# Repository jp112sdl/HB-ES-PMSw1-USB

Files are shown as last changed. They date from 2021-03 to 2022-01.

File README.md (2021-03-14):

# HB-ES-PMSw1-USB
Homebrew Homematic USB Strom-/Spannungsmesser mit INA219

Benötigt [JP-HB-Devices Addon mind. V 4.2](https://github.com/jp112sdl/JP-HB-Devices-addon/releases)

In der Arduino IDE muss noch folgende Lib eingebunden werden:
- https://github.com/jp112sdl/INA219_WE

### Aktueller Stand (14.03.2021):
- CCU Unterstützung bereitgestellt (Addon V 4.2)
- Sketch lauffähig

### schematischer Schaltungsaufbau
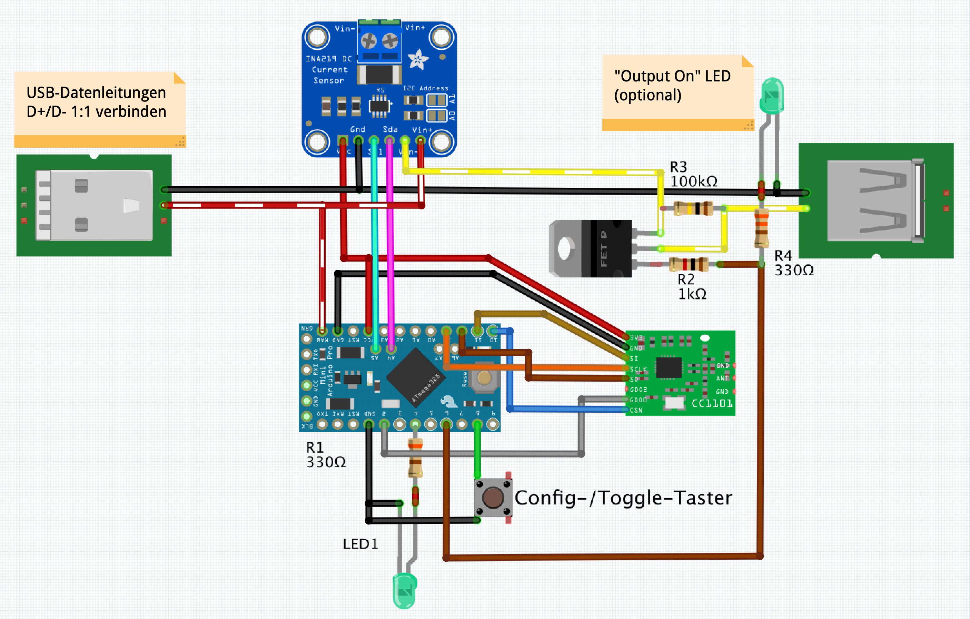
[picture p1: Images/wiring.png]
wiring


###  🚧 PCB - WORK IN PROGRESS

Projekt-Thread im HomeMatic-Forum: https://homematic-forum.de/forum/viewtopic.php?f=76&t=66307

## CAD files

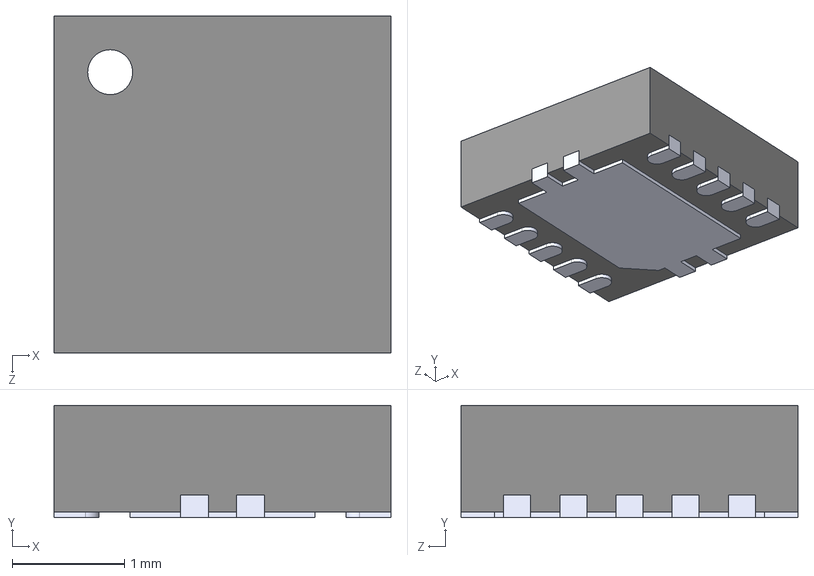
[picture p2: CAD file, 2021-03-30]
PCB/additional/SON50P300X300X100-11N.step
3.00 x 1.00 x 3.00 mm

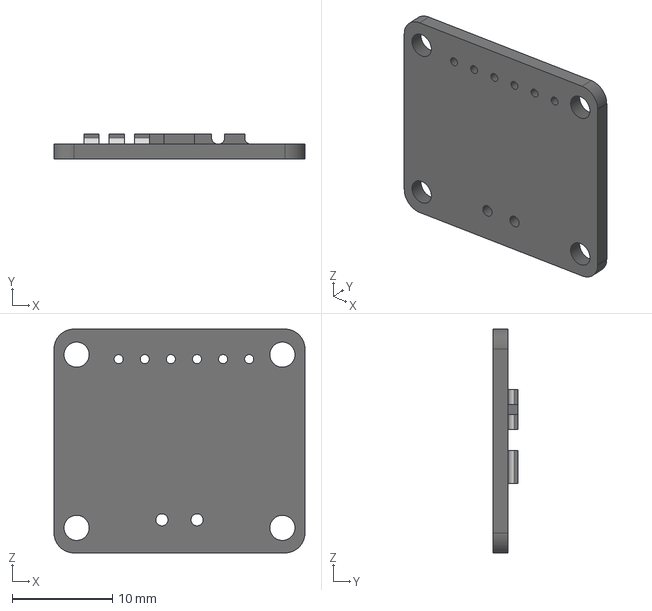
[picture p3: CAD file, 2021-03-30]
PCB_ProMini/additional/CJMCU-219 INA219.step
25.0 x 2.50 x 22.3 mm

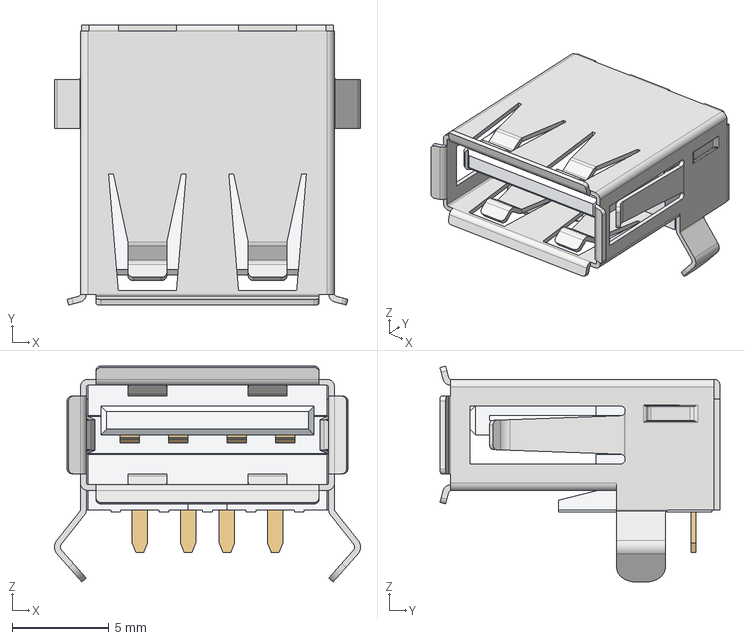
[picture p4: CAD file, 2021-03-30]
PCB/additional/femaleThruHoleUSB.stp
15.8 x 14.4 x 11.1 mm

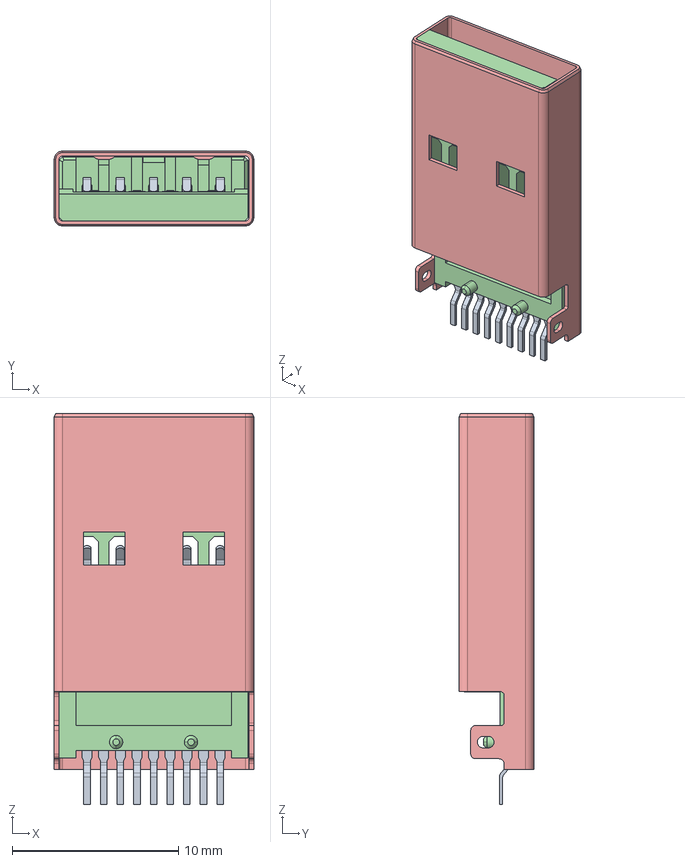
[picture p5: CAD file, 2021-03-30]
PCB_ProMini/additional/usb-male.stp
12.0 x 4.50 x 23.5 mm
CONTACT_5-1
CONTACT-1-1
CONTACT-2-1
CONTACT-3-1
CONTACT-4-1
HOUSING-1
SHELL-SA-1

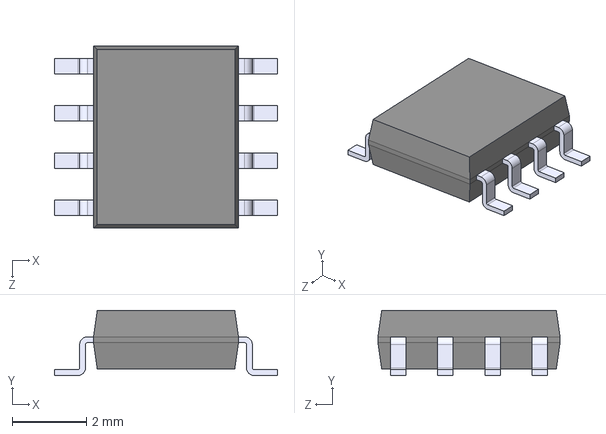
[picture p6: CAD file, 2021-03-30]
PCB/additional/SI9933CDY.STEP
6.00 x 1.75 x 4.90 mm

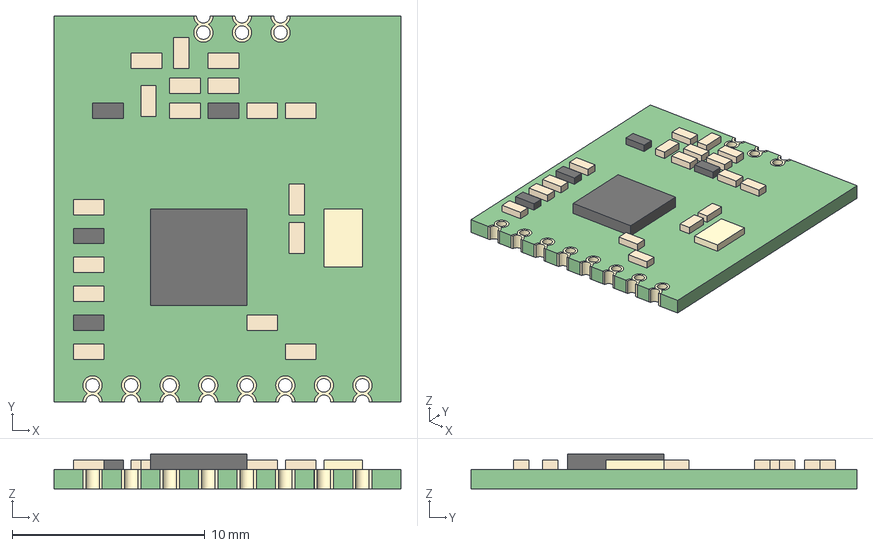
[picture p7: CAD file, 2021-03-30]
PCB/additional/CC1101_Module.step
18.0 x 20.0 x 1.80 mm
PCB
Parts
Pads

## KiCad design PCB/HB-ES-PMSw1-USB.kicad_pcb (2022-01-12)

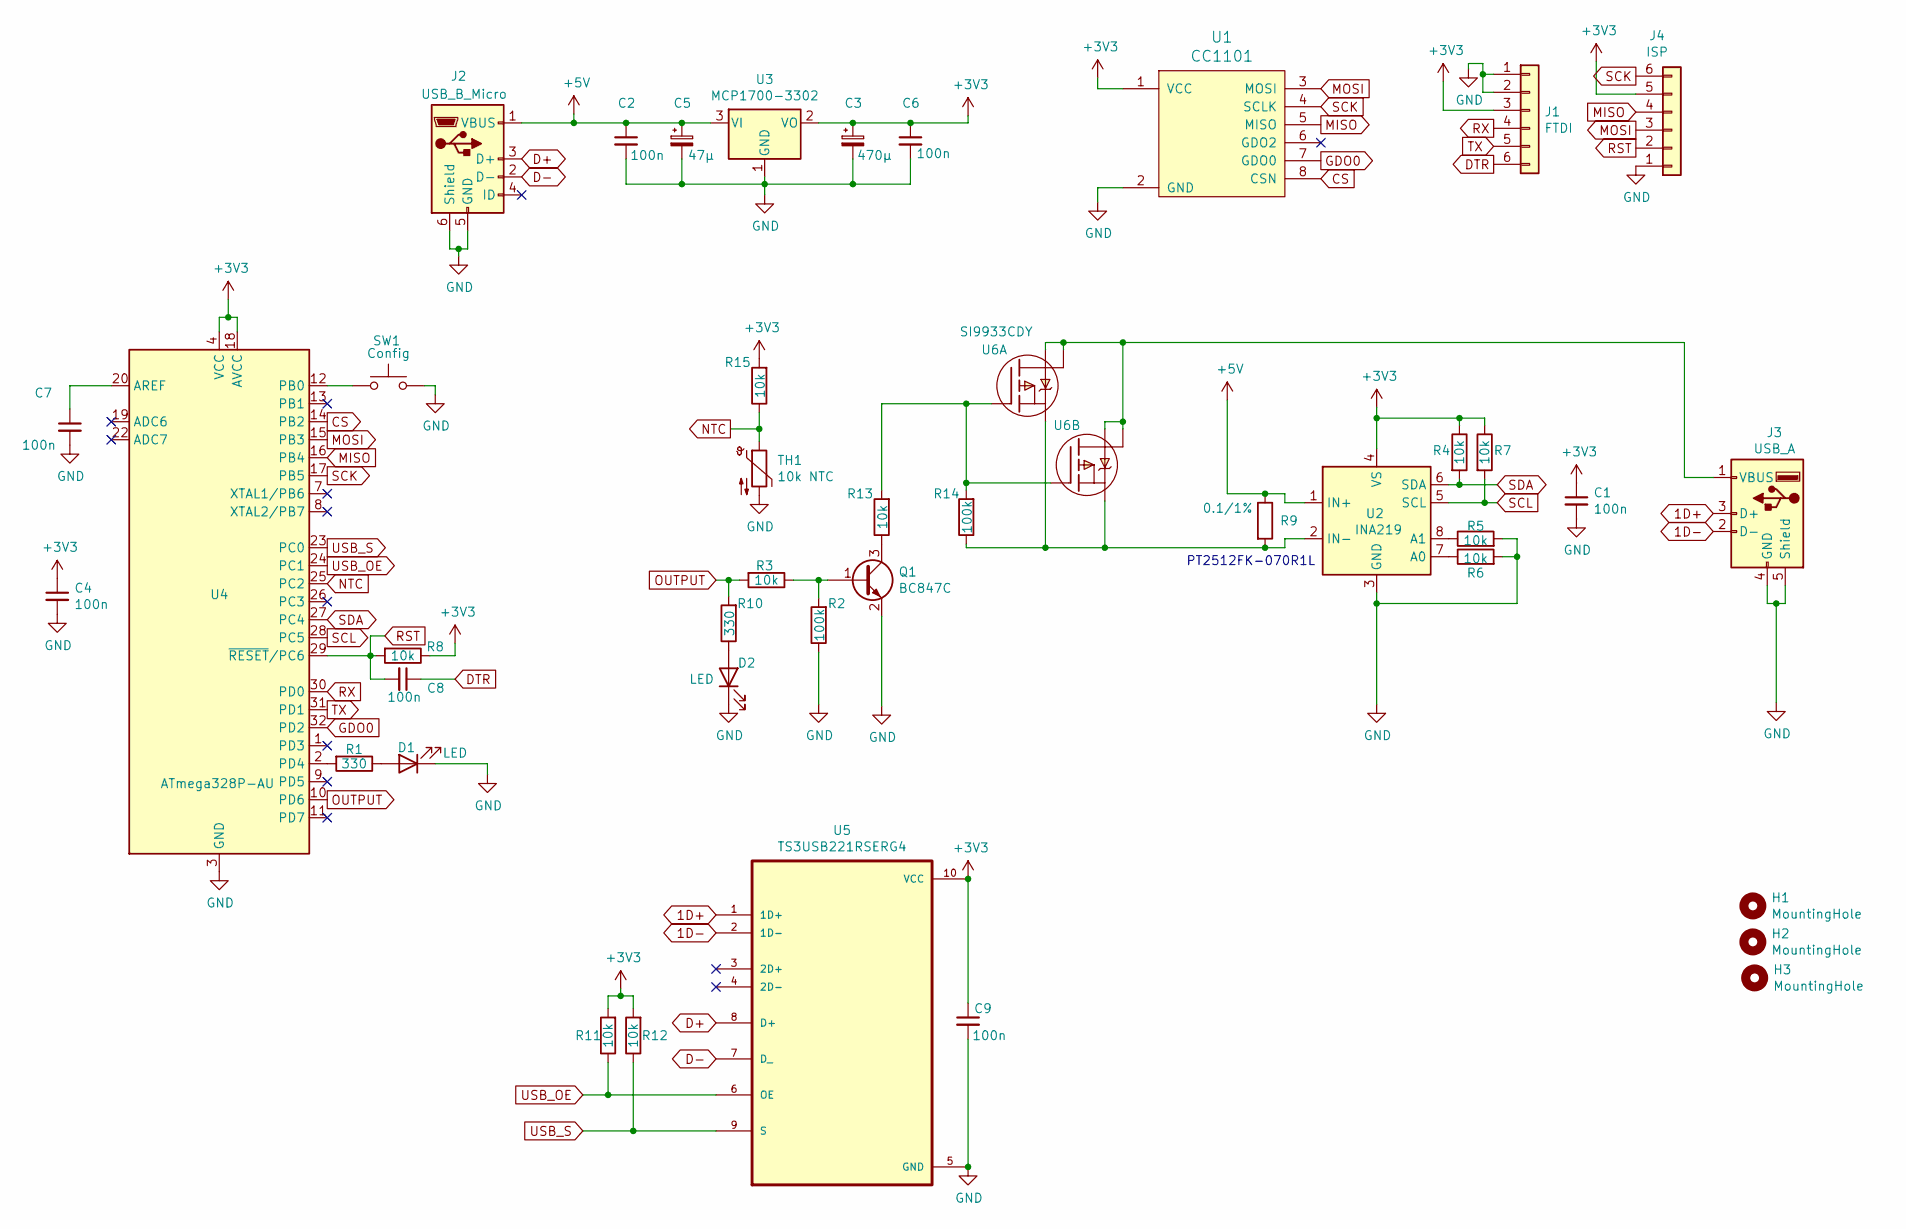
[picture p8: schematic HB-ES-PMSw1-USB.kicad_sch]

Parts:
C1, C2, C4, C6, C7, C8, C9: 100n; C_0805_2012Metric_Pad1.15x1.40mm_HandSolder
C3: 470µ; CP_Elec_8x10.5
C5: 47µ; CP_Elec_8x5.4
D1, D2: LED; LED_0805_2012Metric_Pad1.15x1.40mm_HandSolder
H1, H2, H3: MountingHole; MountingHole_2.7mm_M2.5
J1: FTDI; PinHeader_1x06_P2.54mm_Vertical
J2: USB_B_Micro; USB_Micro-B_Molex-105017-0001
J3: USB_A
J4: ISP; PinPads_ISP
Q1: BC847C; SOT-23
R1, R10: 330; R_0805_2012Metric_Pad1.15x1.40mm_HandSolder
R2, R14: 100k; R_0805_2012Metric_Pad1.15x1.40mm_HandSolder
R3, R4, R5, R6, R7, R8, R11, R12, R13, R15: 10k; R_0805_2012Metric_Pad1.15x1.40mm_HandSolder
R9: 0.1/1%; R_2512_6332Metric_Pad1.52x3.35mm_HandSolder
SW1: Config; SW_PUSH_6mm_H5mm
TH1: 10k NTC; R_0805_2012Metric_Pad1.15x1.40mm_HandSolder
U1: CC1101; CC1101_SMD
U2: INA219; SOT-23-8
U3: MCP1700-3302; SOT-23
U4: ATmega328P-AU; TQFP-32_7x7mm_P0.8mm
U5: TS3USB221RSERG4; SON50P300X300X100-11N
U6: SI9933CDY; SO8-2

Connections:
1D+: J3.3 (D+), U5.1 (1D+)
1D-: J3.2 (D-), U5.2 (1D-)
+3V3: C1.1, C3.1, C4.1, C6.1, C9.1, J1.3, J4.5, R4.1, R7.1, R8.1, R11.2, R12.2, R15.2, U1.1 (VCC), U2.4 (VS), U3.2 (VO), U4.4 (VCC), U4.6 (VCC), U4.18 (AVCC), U5.10 (VCC)
+5V: C2.1, C5.1, J2.1 (VBUS), R9.1, U2.1 (IN+), U3.3 (VI)
CS: U1.8 (CSN), U4.14 (PB2)
D+: J2.3 (D+), U5.8 (D+)
D-: J2.2 (D-), U5.7 (D_)
DTR: C8.1, J1.6
GDO0: U1.7 (GDO0), U4.32 (PD2)
GND: C1.2, C2.2, C3.2, C4.2, C5.2, C6.2, C7.2, C9.2, D1.1 (K), D2.1 (K), J1.1, J1.2, J2.5 (GND), J2.6 (Shield), J3.4 (GND), J3.5 (Shield), J4.1, Q1.2 (E), R2.1, R5.2, R6.2, SW1.2, TH1.2, U1.2 (GND), U2.3 (GND), U3.1 (GND), U4.3 (GND), U4.5 (GND), U4.21 (GND), U5.5 (GND)
MISO: J4.4, U1.5 (MISO), U4.16 (PB4)
MOSI: J4.3, U1.3 (MOSI), U4.15 (PB3)
NTC: R15.1, TH1.1, U4.25 (PC2)
unnamed: C7.1, U4.20 (AREF)
unnamed: D1.2 (A), R1.1
unnamed: D2.2 (A), R10.1
unnamed: J3.1 (VBUS), U6.5, U6.6, U6.7, U6.8
unnamed: Q1.1 (B), R2.2, R3.1
unnamed: Q1.3 (C), R13.1
unnamed: R1.2, U4.2 (PD4)
unnamed: R5.1, U2.8 (A1)
unnamed: R6.1, U2.7 (A0)
unnamed: R13.2, R14.2, U6.2, U6.4
unnamed: R9.2, R14.1, U2.2 (IN-), U6.1, U6.3
unnamed: SW1.1, U4.12 (PB0)
OUTPUT: R3.2, R10.2, U4.10 (PD6)
RST: C8.2, J4.2, R8.2, U4.29 (~RESET/PC6)
RX: J1.4, U4.30 (PD0)
SCK: J4.6, U1.4 (SCLK), U4.17 (PB5)
SCL: R7.2, U2.5 (SCL), U4.28 (PC5)
SDA: R4.2, U2.6 (SDA), U4.27 (PC4)
TX: J1.5, U4.31 (PD1)
USB_OE: R11.1, U4.24 (PC1), U5.6 (OE)
USB_S: R12.1, U4.23 (PC0), U5.9 (S)

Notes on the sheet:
PT2512FK-070R1L

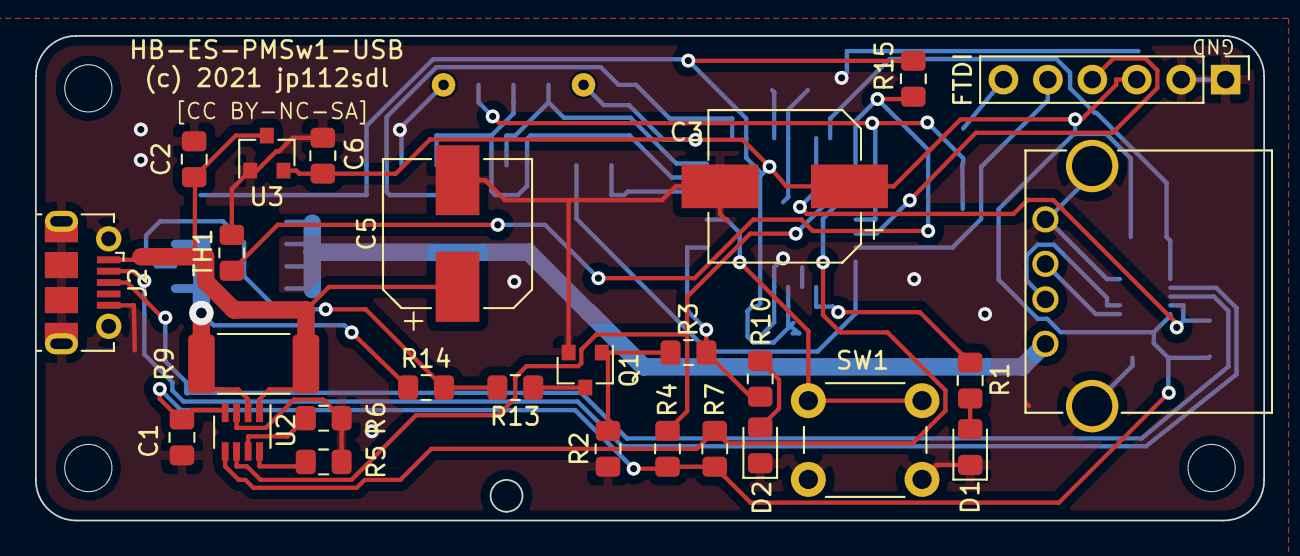
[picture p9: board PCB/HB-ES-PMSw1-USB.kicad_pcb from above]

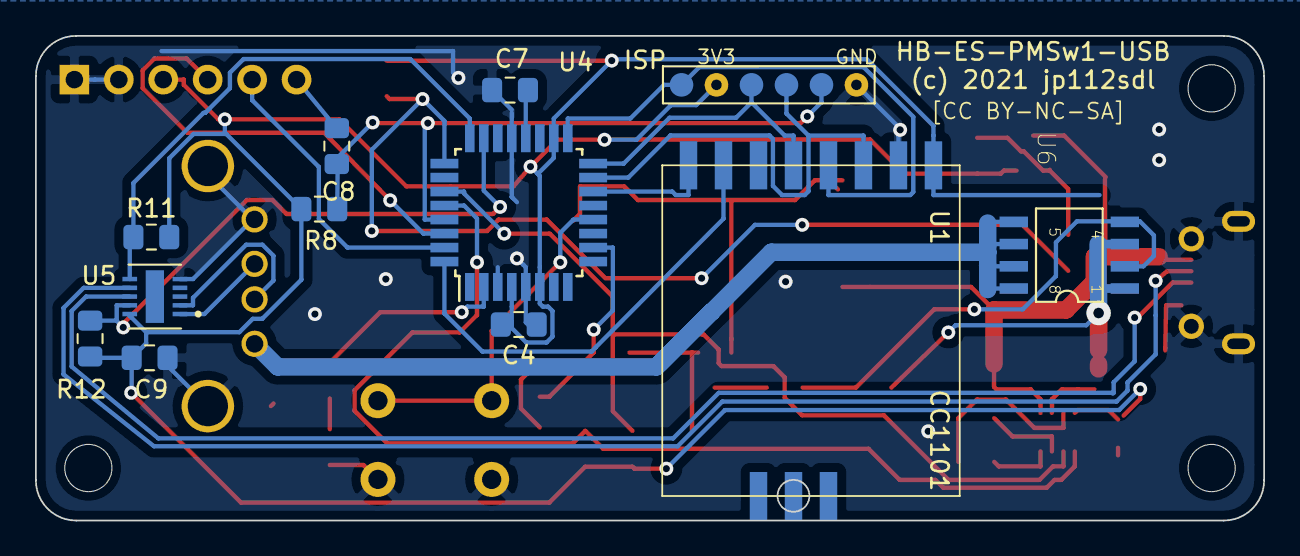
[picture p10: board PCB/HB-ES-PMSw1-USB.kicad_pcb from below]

Board: 2 copper layers, 70.2 x 27.7 mm, 42 parts (12 on the bottom side), 34 nets.

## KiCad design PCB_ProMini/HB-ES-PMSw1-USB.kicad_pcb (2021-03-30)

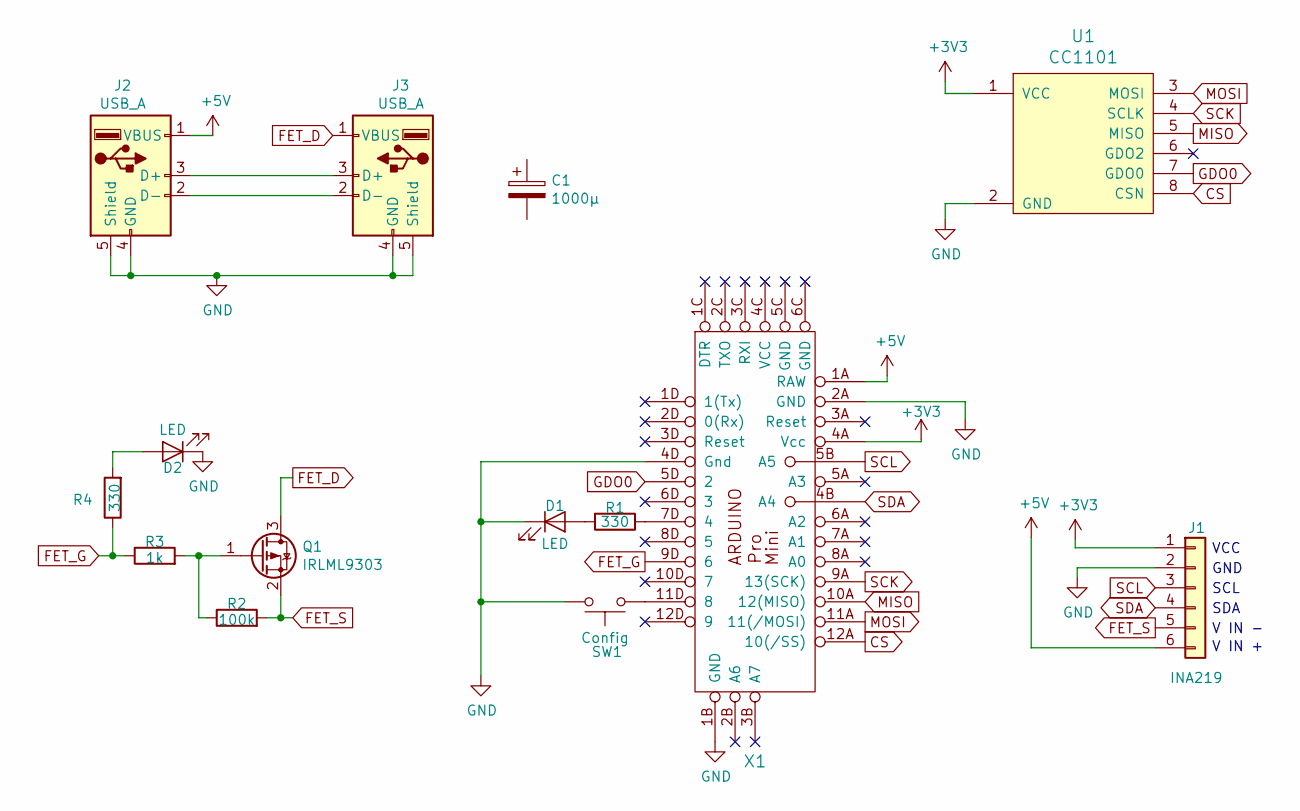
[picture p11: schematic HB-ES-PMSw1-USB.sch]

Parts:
C1: 1000µ; CP_Axial_L29.0mm_D13.0mm_P35.00mm_Horizontal
D1, D2: LED; LED_D3.0mm
J1: INA219; PinHeader_1x06_P2.54mm_Vertical
J2, J3: USB_A
Q1: IRLML9303; TO-220-3_Horizontal_TabDown
R1, R4: 330; R_Axial_DIN0204_L3.6mm_D1.6mm_P7.62mm_Horizontal
R2: 100k; R_Axial_DIN0204_L3.6mm_D1.6mm_P2.54mm_Vertical
R3: 1k; R_Axial_DIN0204_L3.6mm_D1.6mm_P2.54mm_Vertical
SW1: Config; SW_PUSH_6mm_H5mm
U1: CC1101
X1: Arduino_Pro_Mini

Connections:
+3V3: J1.1, U1.1 (VCC), X1.4A (Vcc)
+5V: J1.6, J2.1 (VBUS), X1.1A (RAW)
CS: U1.8 (CSN), X1.12A (10(/SS))
FET_D: J3.1 (VBUS), Q1.3 (D)
FET_G: R3.1, R4.1, X1.9D (6)
FET_S: J1.5, Q1.2 (S), R2.2
GDO0: U1.7 (GDO0), X1.5D (2)
GND: D1.1 (K), D2.1 (K), J1.2, J2.4 (GND), J2.5 (Shield), J3.4 (GND), J3.5 (Shield), SW1.2, U1.2 (GND), X1.1B (GND), X1.2A (GND), X1.4D (Gnd)
MISO: U1.5 (MISO), X1.10A (12(MISO))
MOSI: U1.3 (MOSI), X1.11A (11(/MOSI))
unnamed: D1.2 (A), R1.2
unnamed: D2.2 (A), R4.2
unnamed: J2.2 (D-), J3.2 (D-)
unnamed: J2.3 (D+), J3.3 (D+)
unnamed: Q1.1 (G), R2.1, R3.2
unnamed: R1.1, X1.7D (4)
unnamed: SW1.1, X1.11D (8)
SCK: U1.4 (SCLK), X1.9A (13(SCK))
SCL: J1.3, X1.5B (A5)
SDA: J1.4, X1.4B (A4)

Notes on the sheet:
GND
VCC
SCL
SDA
V IN +
V IN -

Board: 2 copper layers, 13 parts (2 on the bottom side), 20 nets, no tracks yet.

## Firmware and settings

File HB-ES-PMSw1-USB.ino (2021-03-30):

//- -----------------------------------------------------------------------------------------------------------------------
// AskSin++
// 2017-10-24 papa Creative Commons - http://creativecommons.org/licenses/by-nc-sa/3.0/de/
// 2021-03-06 jp112sdl Creative Commons - http://creativecommons.org/licenses/by-nc-sa/3.0/de/
//- -----------------------------------------------------------------------------------------------------------------------
// ci-test=yes board=328p aes=no

// define this to read the device id, serial and device type from bootloader section
// #define USE_OTA_BOOTLOADER
// #define NDEBUG
#define HIDE_IGNORE_MSG

#define EI_NOTEXTERNAL
#include <EnableInterrupt.h>
#include <AskSinPP.h>
#include <LowPower.h>
#include <Switch.h>
#include <INA219_WE.h> //https://github.com/jp112sdl/INA219_WE

#define MEASURE_INTERVAL            1
#define POWERMETER_CYCLIC_INTERVAL  120

#define SWITCH_PIN          6
#define INVERT_SWITCH_PIN   true //true = ACTIVE LOW
#define BUTTON_PIN          8
#define LED_PIN             4
#define NTC                A2

#define USB_OE             A1
#define USB_S              A0

// number of available peers per channel
#define PEERS_PER_SWCHANNEL     8
#define PEERS_PER_PMCHANNEL     8
#define PEERS_PER_SENSORCHANNEL 8

// all library classes are placed in the namespace 'as'
using namespace as;

typedef struct {
  uint16_t Current   = 0;
  uint16_t Voltage   = 0;
} sensorValues;

sensorValues actualValues ;
sensorValues lastValues;
uint8_t averaging = 1;
bool    resetAverageCounting = false;
// define all device properties
const struct DeviceInfo PROGMEM devinfo = {
  {0xf3, 0x5a, 0x01},     // Device ID
  "HBPMSwUSB0",           // Device Serial
  {0xf3, 0x5a},           // Device Model
  0x10,                   // Firmware Version
  as::DeviceType::Switch, // Device Type
  {0x01, 0x00}            // Info Bytes
};

// Configure the used hardware
typedef AvrSPI<10, 11, 12, 13> RadioSPI;
typedef AskSin<StatusLed<LED_PIN>, NoBattery, Radio<RadioSPI, 2> > Hal;
Hal hal;

DEFREGISTER(Reg0, MASTERID_REGS, DREG_INTKEY, DREG_LOCALRESETDISABLE)
class PMSw1List0 : public RegList0<Reg0> {
  public:
    PMSw1List0(uint16_t addr) : RegList0<Reg0>(addr) {}
    void defaults () {
      clear();
    }
};

bool outputOn() {
  return (digitalRead(SWITCH_PIN) == (INVERT_SWITCH_PIN == true ? LOW:HIGH));
}

class TS3USB221 {
public:
  void init() {
    pinMode(USB_OE, OUTPUT);
    pinMode(USB_S,  OUTPUT);

    //set initial state
    digitalWrite(USB_OE, HIGH);
    digitalWrite(USB_S,  LOW);
  }

  void enable() {
    digitalWrite(USB_OE, LOW);
  }

  void disable() {
    digitalWrite(USB_OE, HIGH);
  }

  void enableD1() {
    enable();
    digitalWrite(USB_S, LOW);
  }

  void enableD2() {
    enable();
    digitalWrite(USB_S, HIGH);
  }
};

class SwChannel : public SwitchChannel<Hal, PEERS_PER_SWCHANNEL, PMSw1List0>  {
  protected:
    typedef SwitchChannel<Hal, PEERS_PER_SWCHANNEL, PMSw1List0> BaseChannel;
    TS3USB221 ts3usb221;

  public:
    SwChannel () : BaseChannel() {}
    virtual ~SwChannel() {}


    void init (uint8_t p, bool inv) {
      ts3usb221.init();
      BaseChannel::init(p, inv);
    }

    virtual void switchState(__attribute__((unused)) uint8_t oldstate, uint8_t newstate,uint32_t delay) {
      BaseChannel::switchState(oldstate, newstate, delay);
      if ( newstate == AS_CM_JT_ON ) {
        resetAverageCounting = true;
        ts3usb221.enableD1();
      }
      else if ( newstate == AS_CM_JT_OFF ) {
        ts3usb221.disable();
      }
    }
};
DEFREGISTER(MReg1, CREG_AES_ACTIVE, CREG_AVERAGING, CREG_TX_MINDELAY, CREG_TX_THRESHOLD_CURRENT, CREG_TX_THRESHOLD_VOLTAGE )
class MeasureList1 : public RegList1<MReg1> {
  public:
    MeasureList1 (uint16_t addr) : RegList1<MReg1>(addr) {}
    void defaults () {
      clear();
      txMindelay(8);
      txThresholdCurrent(100);
      txThresholdVoltage(100);
      averaging(1);
    }
};

DEFREGISTER(SensorReg1, CREG_AES_ACTIVE, CREG_LEDONTIME, CREG_TRANSMITTRYMAX, CREG_COND_TX_THRESHOLD_HI, CREG_COND_TX_THRESHOLD_LO, CREG_COND_TX, CREG_COND_TX_DECISION_ABOVE, CREG_COND_TX_DECISION_BELOW)
class SensorList1 : public RegList1<SensorReg1> {
  public:
    SensorList1 (uint16_t addr) : RegList1<SensorReg1>(addr) {}
    void defaults () {
      clear();
      transmitTryMax(6);
      condTxDecisionAbove(200);
      condTxDecisionBelow(0);
      condTxFalling(false);
      condTxRising(false);
      condTxCyclicBelow(false);
      condTxCyclicAbove(false);
      condTxThresholdHi(0);
      condTxThresholdLo(0);
    }
};

class PowerEventMsg : public Message {
  public:
    void init(uint8_t msgcnt, uint8_t typ, uint16_t current, uint16_t voltage ) {
      Message::init(0x0d, msgcnt, typ, (typ == AS_MESSAGE_POWER_EVENT_CYCLIC) ? BCAST : BIDI | BCAST, (current >> 8), (current) & 0xff);
      pload[0] = (voltage >> 8) & 0xff;
      pload[1] = (voltage) & 0xff;
    }
};

class PowerMeterChannel : public Channel<Hal, MeasureList1, EmptyList, List4, PEERS_PER_PMCHANNEL, PMSw1List0>, public Alarm {
    PowerEventMsg msg;
    uint16_t txThresholdCurrent;
    uint16_t txThresholdVoltage;
    uint8_t txMindelay;
  public:
    PowerMeterChannel () : Channel(), Alarm(0), txThresholdCurrent(0), txThresholdVoltage(0), txMindelay(8) {}
    virtual ~PowerMeterChannel () {}
    virtual void trigger (__attribute__ ((unused)) AlarmClock& clock) {
      static uint8_t tickCount = 0;
      tick = seconds2ticks(delay());
      tickCount++;

      uint8_t msgType = 0;

      if (tickCount > (POWERMETER_CYCLIC_INTERVAL / delay()))  {
        msgType = AS_MESSAGE_POWER_EVENT_CYCLIC;
      }

      if ((txThresholdCurrent   > 0) && (abs((int)(actualValues.Current   - lastValues.Current)  ) >= (int)txThresholdCurrent))   msgType = AS_MESSAGE_POWER_EVENT;
      if ((txThresholdVoltage   > 0) && (abs((int)(actualValues.Voltage   - lastValues.Voltage)  ) >= (int)txThresholdVoltage))   msgType = AS_MESSAGE_POWER_EVENT;

      if ((msgType != AS_MESSAGE_POWER_EVENT) && (actualValues.Current > 0) && (lastValues.Current == 0)) msgType = AS_MESSAGE_POWER_EVENT;
      msg.init(device().nextcount(), msgType, actualValues.Current, actualValues.Voltage);
      switch (msgType) {
        case AS_MESSAGE_POWER_EVENT_CYCLIC:
          DPRINTLN(F("PowerMeterChannel - SENDING CYCLIC MESSAGE"));
          tickCount = 0;
          device().broadcastEvent(msg);
          break;
        case AS_MESSAGE_POWER_EVENT:
          if (device().getMasterID() > 0) {
            DPRINTLN(F("PowerMeterChannel - SENDING EVENT MESSAGE"));
            device().sendMasterEvent(msg);
          }
          break;
      }

      lastValues.Current = actualValues.Current;
      lastValues.Voltage = actualValues.Voltage;

      sysclock.add(*this);
    }

    uint32_t delay() {
      return max(1, txMindelay);
    }

    void configChanged() {
      DPRINTLN(F("PowerMeterChannel Config changed List1"));
      txThresholdCurrent   = this->getList1().txThresholdCurrent();      // 1 mA   = 1
      txThresholdVoltage   = this->getList1().txThresholdVoltage();      // 10.0V  = 100
      txMindelay           = this->getList1().txMindelay();
      averaging            = this->getList1().averaging();
      DPRINT(F("txMindelay           = ")); DDECLN(txMindelay);
      DPRINT(F("txThresholdCurrent   = ")); DDECLN(txThresholdCurrent);
      DPRINT(F("txThresholdVoltage   = ")); DDECLN(txThresholdVoltage);
    }

    void setup(Device<Hal, PMSw1List0>* dev, uint8_t number, uint16_t addr) {
      Channel::setup(dev, number, addr);
      sysclock.add(*this);
    }

    uint8_t status () const {
      return 0;
    }

    uint8_t flags () const {
      return 0;
    }
};

class SensorChannel : public Channel<Hal, SensorList1, EmptyList, List4, PEERS_PER_SENSORCHANNEL, PMSw1List0>, public Alarm {
  public:

    SensorChannel () : Channel(), Alarm(0) {}
    virtual ~SensorChannel () {}

    virtual void trigger (__attribute__ ((unused)) AlarmClock& clock) {
      static uint8_t evcnt = 0;
      bool sendMsg = false;
      tick = seconds2ticks(10);

      if (outputOn() == true) {
        SensorEventMsg& rmsg = (SensorEventMsg&)device().message();
        static uint8_t aboveMsgSent = false;
        static uint8_t belowMsgSent = false;
        switch (number()) {
          case 3:
            // Stromsensor
            if (this->getList1().condTxRising() == true)  {
              if (actualValues.Current > this->getList1().condTxThresholdHi()) {
                if ((aboveMsgSent == false && this->getList1().condTxCyclicAbove() == false) || this->getList1().condTxCyclicAbove() == true) {
                  //DPRINT(F("SensorChannel Strom - SENDING condTxRising "));DDECLN(this->getList1().condTxDecisionAbove());
                  rmsg.init(device().nextcount(), number(), evcnt++, this->getList1().condTxDecisionAbove(), false , false);
                  sendMsg = true;
                  aboveMsgSent = true;
                }
              } else {
                aboveMsgSent = false;
              }
            }
            if (this->getList1().condTxFalling() == true) {
              if (actualValues.Current < this->getList1().condTxThresholdLo()) {
                if ((belowMsgSent == false && this->getList1().condTxCyclicBelow() == false) || this->getList1().condTxCyclicBelow() == true) {
                  //DPRINT(F("SensorChannel Strom - SENDING condTxFalling "));DDECLN(this->getList1().condTxDecisionBelow());
                  rmsg.init(device().nextcount(), number(), evcnt++, this->getList1().condTxDecisionBelow(), false , false);
                  sendMsg = true;
                  belowMsgSent = true;
                }
              } else {
                belowMsgSent = false;
              }
            }
            break;
          case 4:
            // Spannungssensor
            if (this->getList1().condTxRising() == true)  {
              if (actualValues.Voltage > this->getList1().condTxThresholdHi()) {
                if ((aboveMsgSent == false && this->getList1().condTxCyclicAbove() == false) || this->getList1().condTxCyclicAbove() == true) {
                  //DPRINT(F("SensorChannel Spannung - SENDING condTxRising "));DDECLN(this->getList1().condTxDecisionAbove());
                  rmsg.init(device().nextcount(), number(), evcnt++, this->getList1().condTxDecisionAbove(), false , false);
                  sendMsg = true;
                  aboveMsgSent = true;
                }
              } else {
                aboveMsgSent = false;
              }
            }
            if (this->getList1().condTxFalling() == true) {
              if (actualValues.Voltage < this->getList1().condTxThresholdLo()) {
                if ((belowMsgSent == false && this->getList1().condTxCyclicBelow() == false) || this->getList1().condTxCyclicBelow() == true) {
                  //DPRINT(F("SensorChannel Spannung - SENDING condTxFalling "));DDECLN(this->getList1().condTxDecisionBelow());
                  rmsg.init(device().nextcount(), number(), evcnt++, this->getList1().condTxDecisionBelow(), false , false);
                  sendMsg = true;
                  belowMsgSent = true;
                }
              } else {
                belowMsgSent = false;
              }
            }
            break;
        }

        if (sendMsg) {
          device().sendPeerEvent(rmsg, *this);
          //DPRINTLN(F("SensorChannel - SENDING done"));
          sendMsg = false;
        }
      }
      sysclock.add(*this);
    }

    void configChanged() {
      /*DPRINT(F("SensorChannel ")); DDEC(number()); DPRINTLN(F(" Config changed List1"));

      DPRINT(F("transmitTryMax      = ")); DDECLN(this->getList1().transmitTryMax());
      DPRINT(F("condTxDecisionAbove = ")); DDECLN(this->getList1().condTxDecisionAbove());
      DPRINT(F("condTxDecisionBelow = ")); DDECLN(this->getList1().condTxDecisionBelow());
      DPRINT(F("condTxFalling       = ")); DDECLN(this->getList1().condTxFalling());
      DPRINT(F("condTxRising        = ")); DDECLN(this->getList1().condTxRising());
      DPRINT(F("condTxCyclicAbove   = ")); DDECLN(this->getList1().condTxCyclicAbove());
      DPRINT(F("condTxCyclicBelow   = ")); DDECLN(this->getList1().condTxCyclicBelow());
      DPRINT(F("condTxThresholdHi   = ")); DDECLN(this->getList1().condTxThresholdHi());
      DPRINT(F("condTxThresholdLo   = ")); DDECLN(this->getList1().condTxThresholdLo());*/
    }

    void setup(Device<Hal, PMSw1List0>* dev, uint8_t number, uint16_t addr) {
      Channel::setup(dev, number, addr);
      sysclock.add(*this);
    }

    uint8_t status () const {
      return 0;
    }

    uint8_t flags () const {
      return 0;
    }
};

class MixDevice : public ChannelDevice<Hal, VirtBaseChannel<Hal, PMSw1List0>, 4, PMSw1List0> {
    class MeasureAlarm : public Alarm {
        MixDevice& dev;
      protected:
        INA219_WE ina219;
      private:
        bool first;
      public:
        MeasureAlarm (MixDevice& d) : Alarm (0), dev(d), first(true) {}
        virtual ~MeasureAlarm () {}

        void initINA219() {
          Wire.begin();
          ina219.init();
          ina219.setBusRange(BRNG_16);
          ina219.setADCMode(SAMPLE_MODE_64);
          //ina219.setPGain(PG_320); //3.2A
          ina219.setPGain(PG_160); //1.6A
        }

        void trigger (AlarmClock& clock)  {
          if (first == true) {
            first = false;
            initINA219();
          }

          set(seconds2ticks(MEASURE_INTERVAL));
          static uint32_t Current    = 0;
          static uint32_t Voltage    = 0;
          static uint8_t  avgCounter = 0;

          if (resetAverageCounting == true) {
            //DPRINTLN(F("*** RESETTING AVERAGING ***"));
            resetAverageCounting = false;
            avgCounter = 0;
            Voltage = 0;
            Current = 0;
          }

          if (avgCounter < averaging) {
            uint32_t v = ina219.getBusVoltage_V();
            //DPRINT("v:");DDECLN(v);
            Voltage += v;
            uint16_t c = ina219.getCurrent_mA();
            //DPRINT("c:");DDECLN(c);
            Current += c;
            avgCounter++;
          } else {
            actualValues.Voltage = (Voltage / averaging);
            actualValues.Current = outputOn() ? (Current / averaging) : 0;
            resetAverageCounting = true;
          }

          clock.add(*this);
        }
    } sensorMeasure;
  public:
    VirtChannel<Hal, SwChannel,         PMSw1List0> c1;
    VirtChannel<Hal, PowerMeterChannel, PMSw1List0> c2;
    VirtChannel<Hal, SensorChannel,     PMSw1List0> c3, c4;
  public:
    typedef ChannelDevice<Hal, VirtBaseChannel<Hal, PMSw1List0>, 4, PMSw1List0> DeviceType;
    MixDevice (const DeviceInfo& info, uint16_t addr) : DeviceType(info, addr), sensorMeasure(*this) {
      DeviceType::registerChannel(c1, 1);
      DeviceType::registerChannel(c2, 2);
      DeviceType::registerChannel(c3, 3);
      DeviceType::registerChannel(c4, 4);

      sysclock.add(sensorMeasure);
    }
    virtual ~MixDevice () {}

    SwChannel& switchChannel ()  {
      return c1;
    }
    PowerMeterChannel& powermeterChannel ()  {
      return c2;
    }
    SensorChannel& sensorChannel3Current ()  {
      return c3;
    }
    SensorChannel& sensorChannel4Voltage ()  {
      return c4;
    }

    virtual void configChanged () {
      DPRINTLN(F("MixDevice Config changed List0"));
    }
};
MixDevice sdev(devinfo, 0x20);
ConfigToggleButton<MixDevice> cfgBtn(sdev);

void initPeerings (bool first) {
  // create internal peerings - CCU2 needs this
  if ( first == true ) {

    HMID devid;
    sdev.getDeviceID(devid);

    Peer current_channel_peer(devid, 3);
    sdev.switchChannel().peer(cfgBtn.peer(), current_channel_peer);

    Peer switch_peer(devid,1);
    sdev.sensorChannel3Current().peer(switch_peer);
  }
}

void setup () {
  DINIT(57600, ASKSIN_PLUS_PLUS_IDENTIFIER);
  bool first = sdev.init(hal);
  sdev.switchChannel().init(SWITCH_PIN, INVERT_SWITCH_PIN);
  buttonISR(cfgBtn, BUTTON_PIN);
  initPeerings(first);
  sdev.initDone();
}

void loop() {
  hal.runready();
  sdev.pollRadio();
}

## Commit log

2021-03-14 add wiring
    [wiring.fzz]
2022-01-12 update kicad
    [HB-ES-PMSw1-USB.kicad_pcb, HB-ES-PMSw1-USB.kicad_sch]

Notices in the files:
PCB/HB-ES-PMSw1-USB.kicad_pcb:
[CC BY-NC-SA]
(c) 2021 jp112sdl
